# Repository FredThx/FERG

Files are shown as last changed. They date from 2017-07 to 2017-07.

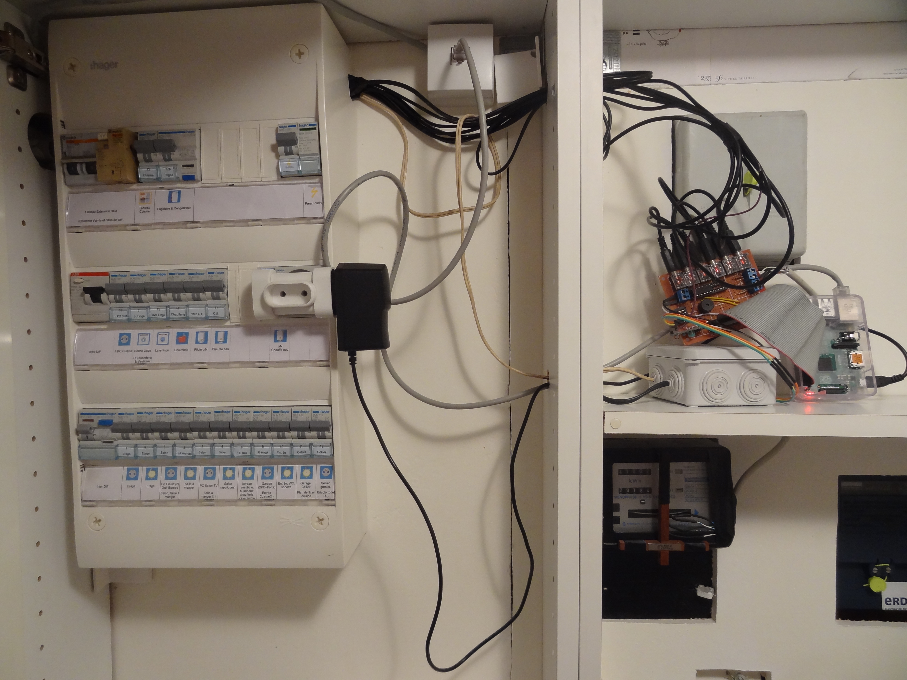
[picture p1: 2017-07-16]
divers/DSC09356.JPG

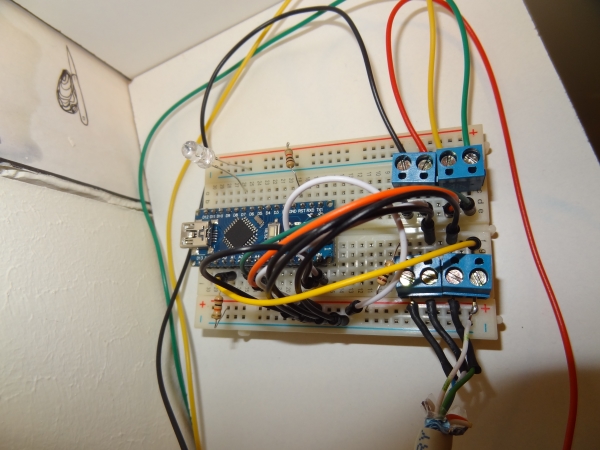
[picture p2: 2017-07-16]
divers/arduino.JPG

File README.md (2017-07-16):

FERG Lib  Une bibliotheque pour Gerer - analyse les energies d'un maison individuelle
========================================================================

	Hardware :
		- Raspberry Pi (ou pcduino)
		- arduino ou atmega328, ou ...
		- compteur edf de type antique (avec une roue)
		- detecteur de bande noire du compteur (détecteur optique QRD1114)
		- tores SCT013 30A
		- detecteur de tension maison (voir schéma) à base de résistance, condensateur, diode et optocoupleur.
		- modules de transmission de données 433 Mhz
		- capteurs de température numériques DS18x20
		- capteur ultrason HRLV MaxSonar EZ pour lecture niveau cuve fuel
		- microcontroleur ATMEGA328 pour gérer les sondes (température, cuve fuel) et envoyer les infos au Rpi
		- convertisseur analogique / numérique MCP3008 pour lecture analogique sur Rpi
		- led, cables, ......
		- eventuellement un serveur nas pour base de données
	
	Software :
		- bibliotheque FGPIO pour gestion de tout le matériel ci-dessus
		- bibliotheque FUTIL pour débogage
		- python avec plein de lib.
		- php, MyQsql

Installation :
     pip install FERG
	 installer la base de données MySQL ou Mariadb ou .....
	 
	 mettre en place les 3 deamons
		- sur Rpi : lecture des températures
		- sur Rpi : lecture du compteur
		- sur serveur Bdd : alertes

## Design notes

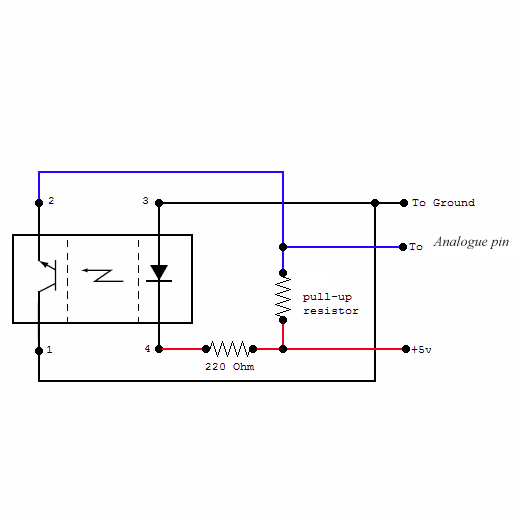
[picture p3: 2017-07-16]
divers/schema qrd1114.png

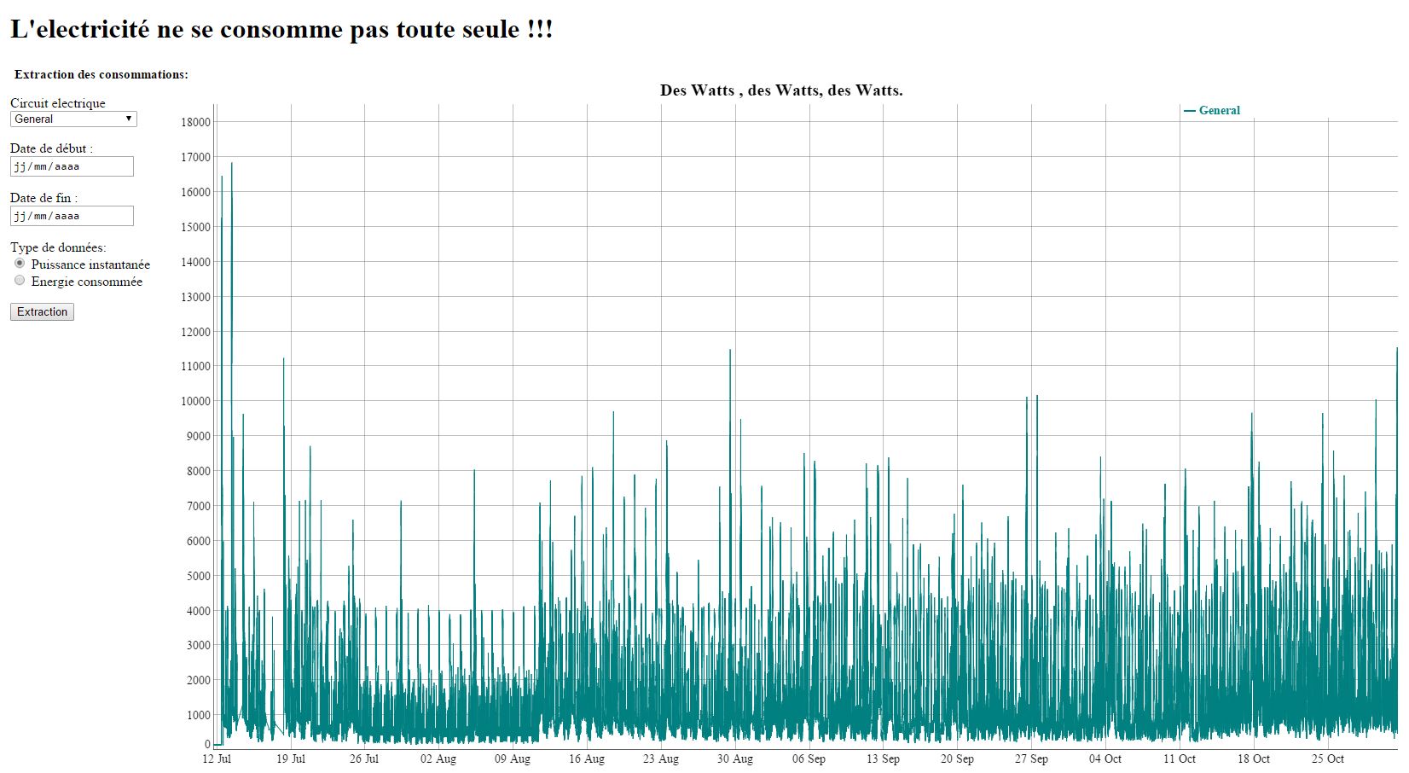
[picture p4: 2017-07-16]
divers/web1.JPG

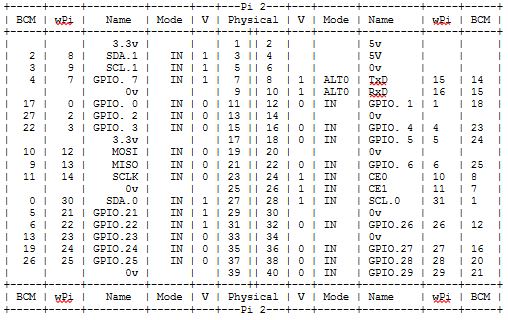
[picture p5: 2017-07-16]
divers/GPIO.JPG

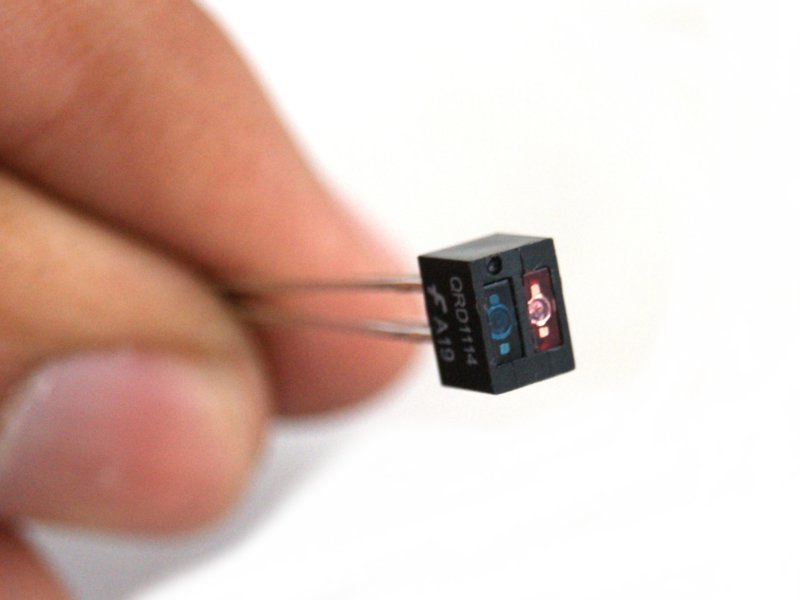
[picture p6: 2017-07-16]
divers/QRD1114.png

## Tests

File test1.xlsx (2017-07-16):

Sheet: test2
1.096725464e-05 | 0.1965820313
0.01045584679 | 0.2094726562
0.02076292038 | 0.1998046875
0.03103399277 | 0.2094726562
0.04130482674 | 0.2030273438
0.05157089233 | 0.20625
0.06184887886 | 0.1965820313
0.07211780548 | 0.2255859375
0.08243203163 | 0.2094726562
0.09270596504 | 0.2223632812
0.1029779911 | 0.20625
0.113255024 | 0.219140625
0.1235249043 | 0.2030273438
0.1337690353 | 0.2288085938
0.1440448761 | 0.2288085938
0.1543209553 | 0.2255859375
0.1645929813 | 0.219140625
0.1749098301 | 0.2384765625
0.1851699352 | 0.2255859375
0.1954808235 | 0.23203125
0.2057759762 | 0.2159179687
0.2160379887 | 0.20625
0.2262918949 | 0.23203125
0.2366609573 | 0.23203125
0.2469089031 | 0.2288085938
0.2572779655 | 0.2610351563
0.2676429749 | 0.2384765625
0.2778890133 | 0.2288085938
0.2881338596 | 0.2352539063
0.2983808517 | 0.2352539063
0.3087699413 | 0.2030273438
0.3190510273 | 0.2094726562
0.3292968273 | 0.2030273438
0.3396689892 | 0.2030273438
0.3499379158 | 0.1998046875
0.3601818085 | 0.20625
0.3704268932 | 0.2094726562
0.380671978 | 0.193359375
0.3909168243 | 0.20625
0.4011619091 | 0.193359375
0.4115149975 | 0.1998046875
0.4218029976 | 0.1901367187
0.4320499897 | 0.193359375
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

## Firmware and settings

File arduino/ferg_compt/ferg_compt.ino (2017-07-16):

/***************************************************************************
 * Projet : FERG
 *          Vieux compteur EDF connecte
 * *************************************************************************
 *      Il s'agit ici de lire un capteur optique 
 *      placé devant la roue du compteur EDF. Et de renvoir 
 *      à un rasperry pi via i2c le nb de tours detectés
 * 
 *      l'arduino (ou atmega328) est en mode esclave
 *        quand il reçoit une demande de lecture, il renvoie le nb de tours 
 *        detecte depuis la derniere demande.
 * 
 *      A l'initialisation, il scan le capteur pour determiner le seuil de déclenchement.
 *      S'il reçoit via i2c la commande RESET = "88", il relance ce calcul.
 ****************************************************************************
 * Auteur : FredThx
 * Date : 15/11/2015
 * **************************************************************************
 */



#include <Wire.h>
#define MY_I2C_ADDR 0x12// Adresse i2c
#define LED 8           // led pour visualiser la detection
#define CAPTEUR 0       // Capteur sur l'entree analogique 'A0'
#define INTERVAL_MES 7  // en milisecondes entre 2 mesures
#define DURATION 20     // Durée minimum en millisecondes pour  valider un detection
#define TIMEOUT 60      // Nb de secondes du tour le plus lent
#define RESET 88        // Ordre de reset



/*
 * Variables Globales
 */
unsigned short int nb_tours = 0;
int seuil_bande ;
unsigned long time_last_detect;
bool on_setup ; // définit s'il faut calculer le seuil de detection (true) ou mesurer (false)

/*
 * Initialisation
 */
void setup() {
    Serial.begin(9600);
    on_setup = true;
	  Wire.begin(MY_I2C_ADDR);
    Wire.onReceive(receiveData);
    Wire.onRequest(sendData);
    pinMode(LED,OUTPUT);
    led_off();
    on_setup = true;
    time_last_detect = millis();
}

/*
 * Main
 *  lecture du capteur 
 *    si le voltage dépasse le seuil plus longtemps que DURATION
 *    on compte un tour de plus.
 */
void loop() {
	if (on_setup){
    seuil_bande = mesure_seuil();
	}else{
	   unsigned long t0;
	   unsigned long t1;
	   t0 = millis();
	   t1 = millis();
	   while ((analogRead(CAPTEUR)> seuil_bande) and ((t1 - t0 < TIMEOUT * 50))){
		  t1 = millis();
	   }
	   if ((t1 - t0 >= TIMEOUT * 500)){
		    //Si timeout, on recalcul de seuil de detection (qui doit ,être trop bas)
        Serial.println("Bande noire trop longue. Le seuil doit etre trop bas.");
		    nb_tours = 201;
		    on_setup = true;
		    t1 = millis();
		    time_last_detect = t1;
	   }else{
		    if ((t1-t0)>DURATION){
			    led_on();
			    nb_tours +=1;
			    delay(INTERVAL_MES * 10);
			    time_last_detect = t1;
		      led_off();
		    }
	   }
	   if ((t1 - time_last_detect) > TIMEOUT * 2000){
		    //Si timeout, on recalcul de seuil de detection (qui doit ,être trop haut)
        Serial.println("Pas de detection dans le temps imparti. Le seuil doit etre trop haut");
		    on_setup = true;
		    time_last_detect = millis();
	   }
	  delay(INTERVAL_MES);
	}
}


/*
 * Deamon sur reception de donnees via i2c
 *    Si reception de RESET : recalcul du seuil
 */
void receiveData(int byteCount){
    int dataReceived;
    Serial.println("Donnees recues du serveur i2c.");
    while(Wire.available()) {
        dataReceived = Wire.read();
        if (dataReceived == RESET){
          Serial.println("Initialisation demandee par le Serveur i2c.");
          nb_tours = 0;
          on_setup = true; //demande un recalcul du seuil de detection
        }
    }
}

/*
 * Deamon sur demande de donnees via i2c
 */
void sendData(){
	if (not on_setup){
		unsigned short int nb_tours_to_send = 0;
		if (nb_tours > 0){
		  if (nb_tours < 255){
			nb_tours_to_send = nb_tours;
		  } else{
			nb_tours_to_send = 255;
		  }
		  nb_tours -= nb_tours_to_send;
     Serial.print("i2c_write : ");
     Serial.println(nb_tours_to_send);
		  Wire.write(nb_tours_to_send);
		}
	} else {
		Wire.write(0);
	}
}

/*
 * Mesure du seuil de detection
 *    quand la bande noire passe devant le capteur, le voltage augmente
 *    ici, on determine le seuil de detection
 */
int mesure_seuil(){
  //Mesure pendant TIMEOUT secondes
  Serial.println("Calcul du seuil de detection de bande noire.");
  int maxi;
  double moyenne;
  int mesure;
  int i = 0;
  unsigned long t0;
  unsigned long t1;
  unsigned long pause;
  led_on();
  t0 = millis();
  t1 = millis();
  maxi = analogRead(CAPTEUR),
  moyenne = analogRead(CAPTEUR);
  while (((t1-t0)/1000 < TIMEOUT) and (t0<=t1)){
    mesure = analogRead(CAPTEUR);
    maxi = max(maxi, mesure);
    moyenne = moyenne*i + mesure;
    i++;
    moyenne /= i;
    //Serial.print("Maxi :");
    //Serial.print(maxi);
    //Serial.print(" Moyenne :");
    //Serial.print(int(moyenne));
    Serial.print(" mesure(");
    Serial.print(i);
    Serial.print(") : ");
    Serial.println(mesure);
    //Serial.print(" . temps :");
    //Serial.println(int((t1-t0)/1000));
    t1 = millis();
  }
  led_off();
  on_setup = false;
  Serial.print("Seuil mesure : ");
  Serial.println(moyenne + (maxi - moyenne)*0.75);
  Serial.print("Pour une moyenne de : ");
  Serial.println(moyenne);
  return moyenne + (maxi - moyenne)*0.75;
}

/*
 * Gestion de la LED
 */
void led_on(){
  digitalWrite(LED,HIGH);
}

void led_off(){
  digitalWrite(LED,LOW);
}

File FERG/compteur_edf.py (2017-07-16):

#!/usr/bin/env python
# -*- coding:utf-8 -*

#Pour travailler sur les sources
import sys
sys.path.insert(0,'../../FGPIO')
sys.path.insert(0,'../../FUTIL')

from FGPIO.qrd1114_io import *
from FGPIO.mcp300x_hspi_io import *
from FGPIO.led_io import *
from FGPIO.bt_io import *
from FGPIO.i2c_device_io import *

import time
import datetime
import logging

#TODO : créer start_record()
#		gestion HC/HP

class compteur_edf(object):
	'''Un compteur EDF avec une grosse roue qui tourne
		Sur lequel on va pouvoir calculer les consos a l'aide d'un capteur qrd1114 placé devant la roue
		qui va détecter le passage de la bande noire.
	'''
	timeout = 60		#Correspond à 150Watts
	time_pause = 0.001	#duree pause entre chaque mesure
	micro_controleur_RESET = 88		#Ordre de reset du micro controleur
	def __init__(self, capteur = None, micro_controleur = None, capteur_hc = None, led = led_io(), intensity_max=45, energy_tr=2.5, nb_tours_mesure = 1, counter_hc = 0.0, counter_hp = 0.0, led_hc = led_io()):
		'''Initialisation
			- capteur			: 	qrd1114_io sur la roue (optionnel) (remplace le micro_controleur)
			- micro_controleur	:	micro controleur pour mesure nb de tours (optionnel) (remplace le capteur optique)
			- capteur_hc		:	capteur d'heure creuse (class bt_io)
			- intensite_max		:	intensité maximum de l'abonnement
			- energy_tr			:	energie par tour de roue en Wh/tr
			- led				:	led pour une impulsion par tour
			- nb_tours_mesure	:	Nb de tour de roue utilisés pour réaliser la mesure
			- counter_hc		:	Compteur Heures creuse en Kwatt
			- counter_hp		:	Compteur Heures pleines en Kwatt
		'''
		if micro_controleur==None:
			assert isinstance(capteur, qrd1114_analog_io), "capteur must be a qrd1114_analog_io"	
		self.capteur = capteur
		if capteur==None:
			assert isinstance(micro_controleur, i2c_device_io), "capteur must be a i2c_device_io"	
		self.micro_controleur = micro_controleur
		assert capteur_hc == None or isinstance(capteur_hc, bt_io), "capteur_hc must be a bt_io"
		self.capteur_hc = capteur_hc
		assert isinstance(led, led_io), "led must be a led_io"
		self.led = led
		self.energy_tr = energy_tr
		self.mini_tr = 3600. / (intensity_max * 230)*self.energy_tr
		self.mini_noir = self.mini_tr *2.5/100*0.4 # durée mini du trait noir qui correspond à 2.5% du cercle -60% de marge
		self.nb_tours_mesure = nb_tours_mesure
		self.seuil_delestage = intensity_max * 230 * 0.90 # à 90% du max
		self.counter_hc = counter_hc
		self.counter_hp = counter_hp
		self.terminated = False #Pour tuer l'enregistrement
		self.led_hc = led_hc
		# Creation d'une thread pour gestion led heure creuses
		if capteur_hc:
			self.capteur_hc.add_thread(on_changed = self.on_capteur_hc_change, pause = 1)
		
	def stop(self):
		'''Stoppe les threads associés au compteur
		'''
		if self.capteur_hc:
			self.capteur_hc.stop()
	
	def init_params(self):
		''' Calcul les paramètres de détection
		'''
		calculated = False
		while not calculated:
			logging.info("Mesure des paramètres du capteur......")
			self.led.blink(0.2)
			moyenne = 0
			maxi = 0
			nb = 0
			fin = time.time() + self.timeout
			while (maxi < moyenne * 5  or nb < 100) and time.time() < fin:
				value = self.capteur.read()
				moyenne = moyenne*nb+value
				nb+=1
				moyenne /= nb
				if value > maxi:
					maxi = value
					logging.debug("Voltage maxi : %s" % maxi)
				time.sleep(self.time_pause)
			self.voltage_moyen = moyenne
			self.gain_seuil = 1 + (maxi / moyenne - 1) * 0.50	# On se laisse une petite marge de 50%
			self.led.stop()
			if self.gain_seuil < 1.25:
				logging.warning("Seuil de detection de bande noire insuffisant.")
			else:
				logging.info( "Voltage_moyen : %.4f - Voltage maxi : %.4f - Seuil : %.4f"%(self.voltage_moyen, maxi, self.voltage_moyen*self.gain_seuil))
				calculated = True
	
	
	def init_record(self):
		'''Doit être lancée avant la première mesure
		'''
		if self.capteur:
			#Si capteur optique
			logging.info("Initialisation du capteur optique.")
			self.init_params()
			self.wait_for_black()
			logging.info("Initialisation du capteur optique ok")
		elif self.micro_controleur:
			#Si micro controleur
			# TODO : attention ici, dés que l'on demarre, on RAZ le µc : s'il y avait des watts dans le µc, c'est perdu!!
			# on peut faire mieux!!!!!!
			# D'un autre coté si on connait le nb de watts, mais pas le temps qu'il a fallut....
			# Dans ce cas, il faudrait rechercher dans la BDD la dernière mesure 
			# En gros : ca fait du boulot!!!! on laisse en TODO...
			logging.info("Initialisation du micro_controleur...")
			connection = False
			while not connection:
				try:
					self.micro_controleur.device.write_cmd(self.micro_controleur_RESET) 
					# Attente de la reponse du micro_controleur
					while self.micro_controleur.device.read()==0:
						time.sleep(1)
					connection = True
				except IOError:
					logging.error("Connection au micro_controleur impossible. Retry in 10 seconds.")
					time.sleep(10)
			logging.info("Initialisation du micro_controleur ok.")
			
	def record(self, rec_function):
		'''Boucle infinie pour mesures et enregistrement
			- rec_function		:		function qui va prendre les donnees en entrée
		'''
		if self.capteur:
			#Si capteur optique
			self.record_optique(rec_function)
		elif self.micro_controleur:
			#Si micro controleur pour lecture nb de tours
			self.record_micro_controleur(rec_function)
		
	
	def record_capteur(self, rec_function):
		'''Boucle infinie pour mesures et enregistrement
			- rec_function		:		function qui va prendre les donnees en entrée
		'''
		logging.debug('compteur_edf.record() start.')
		_power = 0
		i = 0
		while i<self.nb_tours_mesure and not self.terminated:
			i+=1
			now = time.time()
			self.led.on()
			time.sleep(self.mini_tr/2)
			self.led.off()
			self.wait_for_black()
			duree = time.time() - now
			_power += self.energy_tr*3600/duree
		if not self.terminated:
			self.record_tours(self.nb_tours_mesure, time.time() - now, rec_function)
	
	def record_micro_controleur(self, rec_function):
		'''Boucle infinie pour mesures et enregistrement
			- rec_function		:		function qui va prendre les donnees en entrée
		'''
		now = time.time()
		logging.debug('compteur_edf.record() start.')			
		nb_tours_enregistres = 0
		while nb_tours_enregistres < self.nb_tours_mesure and not self.terminated:
			nb_tours_lu = self.micro_controleur.device.read()
			if nb_tours_lu > 0:
				self.led.on()
				logging.debug('Lecture du micro_controleur : %s tour(s)' % nb_tours_lu)
				nb_tours_enregistres+=nb_tours_lu
			time.sleep(self.mini_tr)
			self.led.off()
		if not self.terminated:
			self.record_tours(nb_tours_enregistres, time.time() - now, rec_function)
			
	def record_tours(self, nb_tours, duree, rec_function):
		'''Enregistre un nb de tours 
		'''
		logging.debug('%s tour enregistres.' % nb_tours)
		# Calcul Energie et puissance
		energy = self.energy_tr * nb_tours
		power = energy * 3600 / duree
		# Mise à jours des compteurs (HC et HP)
		if self.type_horaire() == 'HC':
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
